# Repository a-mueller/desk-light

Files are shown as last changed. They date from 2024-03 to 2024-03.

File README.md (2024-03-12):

# Desk Light

This is most likely useless for anyone else, hosting it here in case I need to make another one at some point.

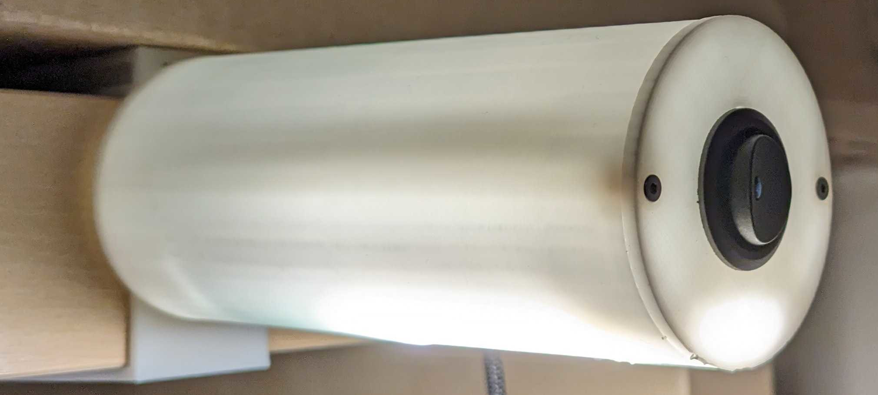
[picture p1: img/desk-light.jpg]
Desk Light


## 3D Models

found in `3dPrinting`

## Board

See KiCad files.

### Schematic

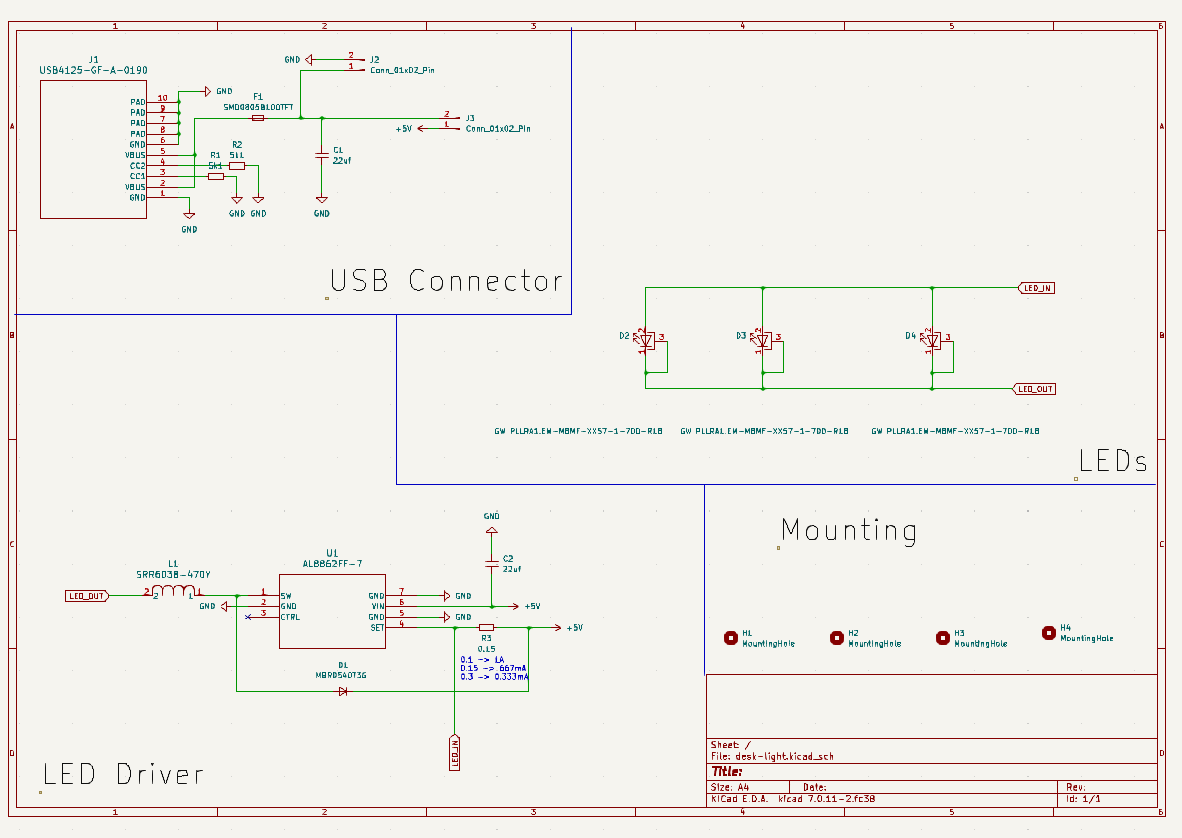
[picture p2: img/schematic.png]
Schematic


### PCB

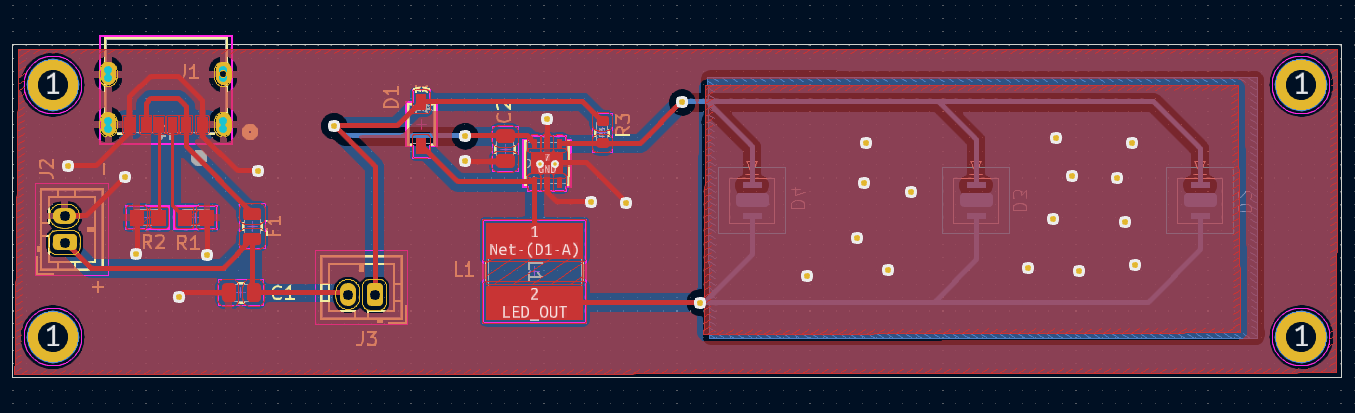
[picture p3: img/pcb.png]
PCB


### BOM

<table>
<tr><td>R1,R2</td><td>5.1k, 0603</td><td></td></tr>
<tr><td>J1</td><td>USB4125-GF-A-0190</td><td>https://uk.farnell.com/global-connector-technology/usb4125-gf-a-0190/usb-conn-type-c-r-a-rcpt-6pos/dp/3777661</td></tr>
<tr><td>J2</td><td>JST PH 2.0 mm</td><td>alternative power, in case no USB connector used</td></tr>
<tr><td>J3</td><td>JST PH 2.0 mm</td><td>On / off switch</td></tr>
<tr><td>C1, C2</td><td>22uf, 0805</td><td></td></tr>
<tr><td>F1</td><td>Fuse 0805, 1A/1.95A</td><td>https://uk.farnell.com/yageo/smd0805b100tft/pptc-reset-fuse-smd-6vdc-0805/dp/4072028?st=smd0805b100tft</td></tr>
<tr><td>D1</td><td>Diode, MBR0540T3G 0.5A, SOD 123</td><td>https://uk.farnell.com/on-semiconductor/mbr0540t3g/diode-schottky-0-5a-40v-sod-123/dp/2101839?st=mbr0540t3g</td></tr>
<tr><td>U1</td><td>Led Driver, AL8862FF-7, 1A</td><td>https://uk.farnell.com/diodes-inc/al8862ff-7/led-dc-dc-driver-buck-u-dfn3030/dp/3946403?st=al8862ff-7</td></tr>
<tr><td>R3</td><td>0.15ohm, 0603</td><td>sets output to 1A</td></tr>
<tr><td>L1</td><td>Inductor, SRR6038-470Y</td><td>https://uk.farnell.com/bourns/srr6038-470y/power-inductor-47uh-0-95a-shielded/dp/2859255?st=srr6038-470y</td></tr>
<tr><td>D2,D3,D4</td><td>LEDs power, GW PLLRA1.EM-M8MF-XX57-1-700-R18</td><td>https://uk.farnell.com/osram-opto-semiconductors/gw-pllra1-em-m8mf-xx57-1-700/led-hb-warm-white-3000k-280lm/dp/3625393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</td></tr>

</table>

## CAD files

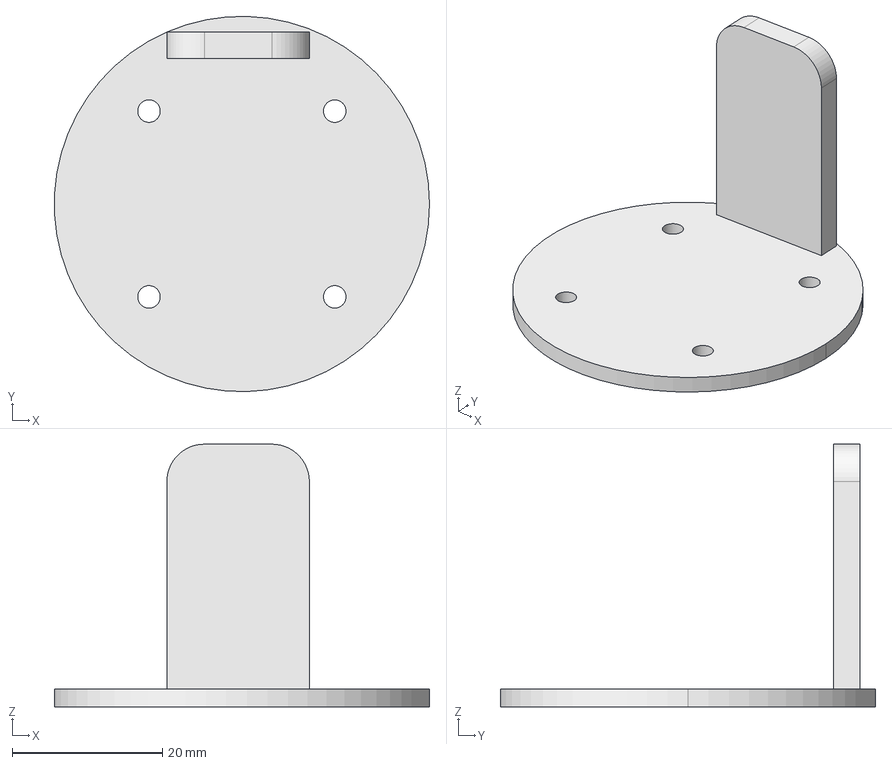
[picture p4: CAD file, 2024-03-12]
3dPrinting/desk-light-v1.FCStd
50.0 x 50.0 x 35.0 mm

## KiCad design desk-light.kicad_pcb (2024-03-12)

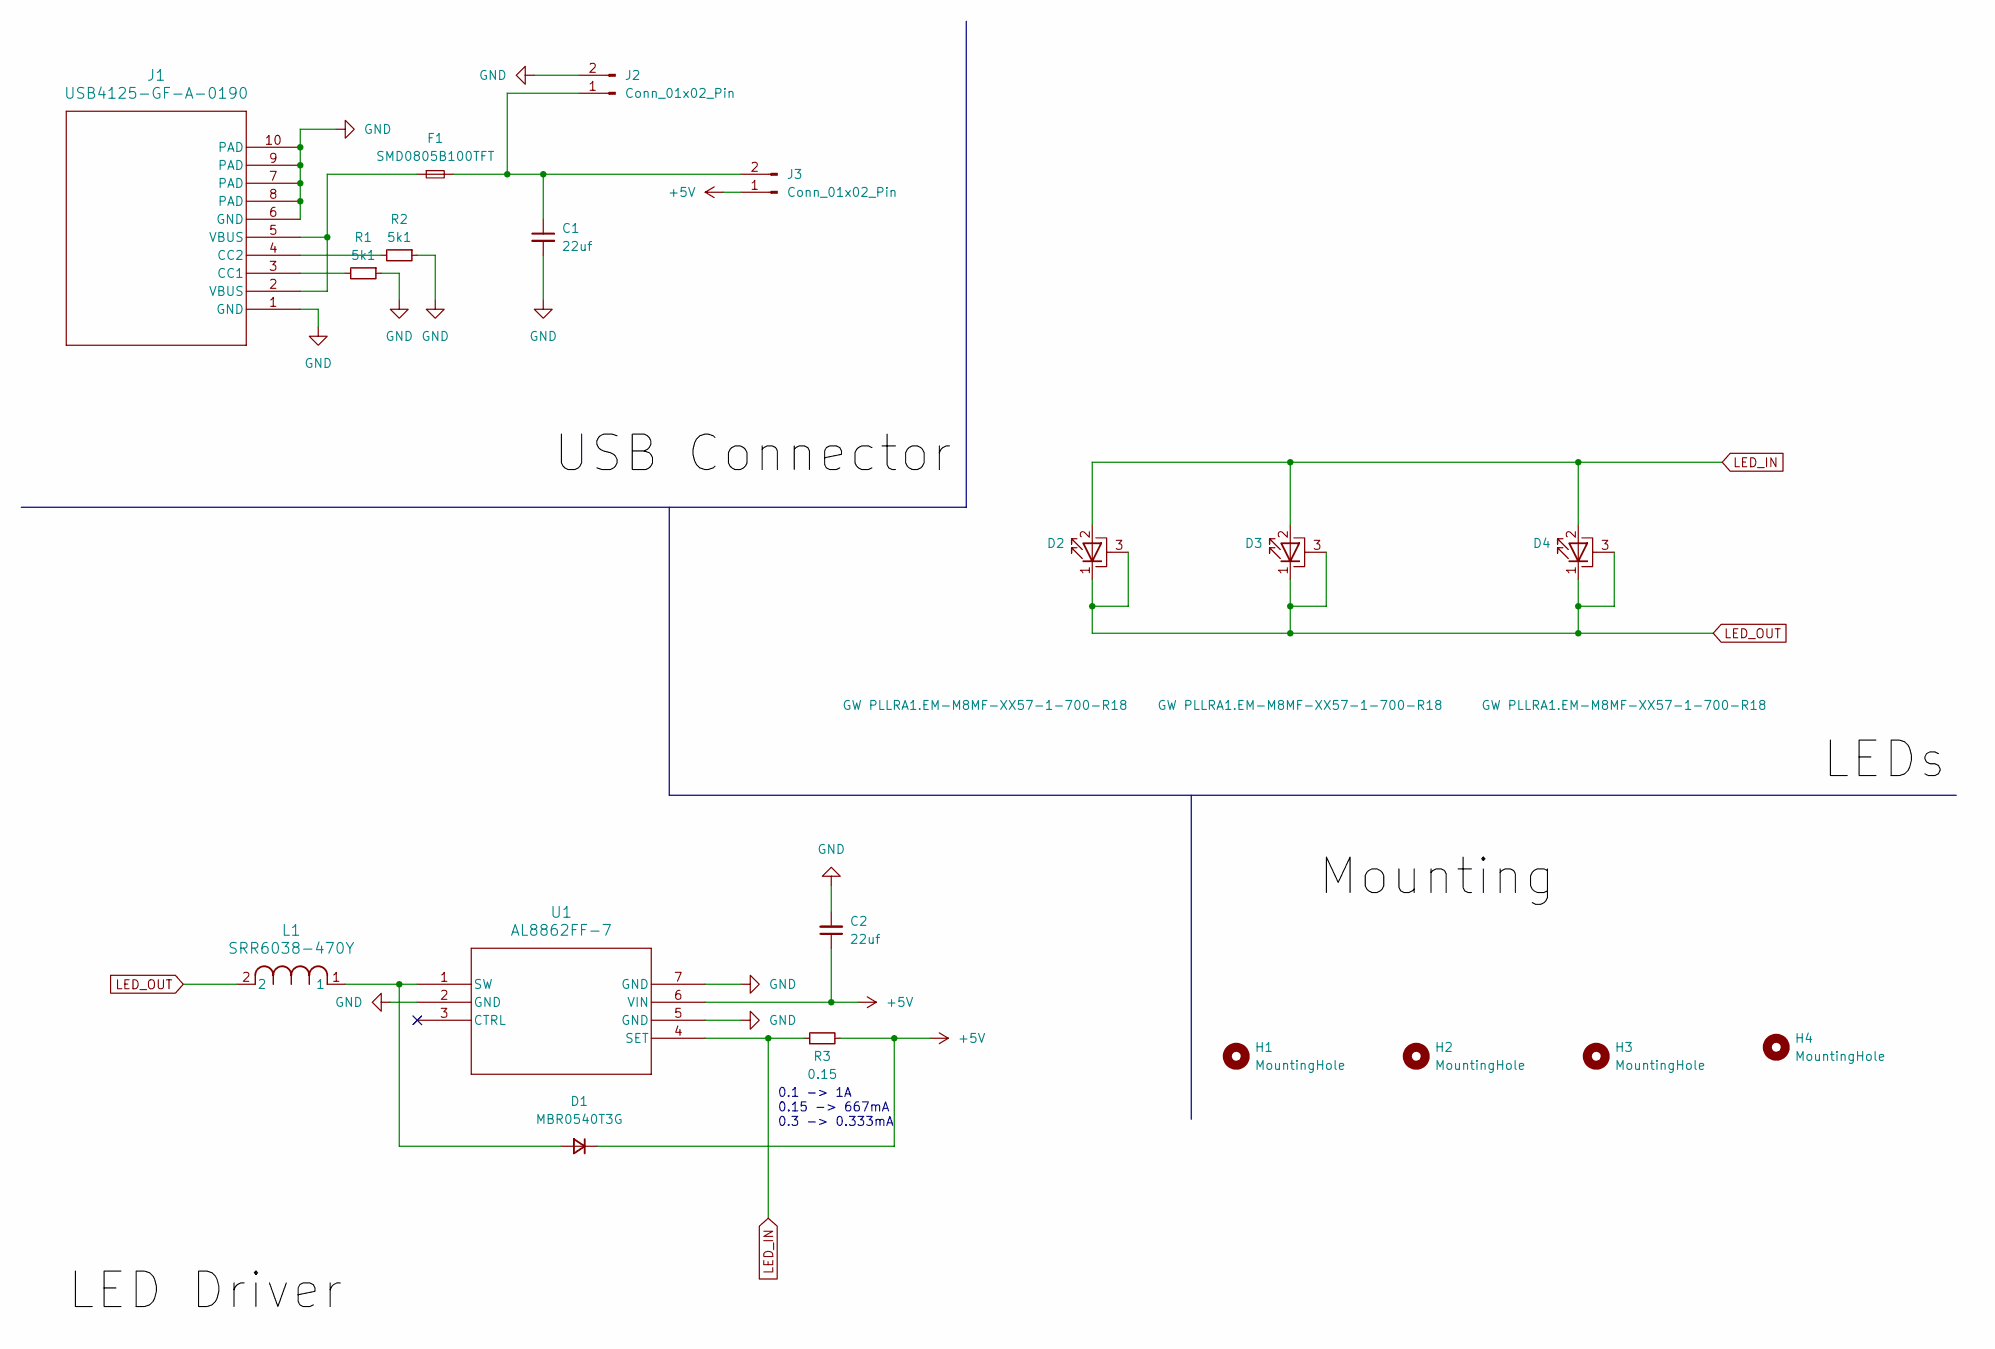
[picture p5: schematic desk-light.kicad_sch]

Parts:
C1, C2: 22uf; C_0805_2012Metric
D1: MBR0540T3G; SOD-123_ONS
D2, D3, D4: GW PLLRA1.EM-M8MF-XX57-1-700-R18; GWPLLRA1.EM
F1: SMD0805B100TFT; Fuse_0805_2012Metric
H1, H2, H3, H4: MountingHole; MountingHole_2.2mm_M2_DIN965_Pad
J1: USB4125-GF-A-0190; CONN6_125-GF-A-0190_GCT
J2, J3: Conn_01x02_Pin; JST_PH_B2B-PH-K_1x02_P2.00mm_Vertical
L1: SRR6038-470Y; IND_BOURNS_SRR6038
R1, R2: 5k1; ERJ6G_PAN
R3: 0.15; R_0603_1608Metric
U1: AL8862FF-7; U-DFN3030-6_DIO

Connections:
+5V: C2.1, D1.1 (K), J3.1, R3.2, U1.6 (VIN)
GND: C1.2, C2.2, J1.1 (GND), J1.6 (GND), J1.7 (PAD), J1.8 (PAD), J1.9 (PAD), J1.10 (PAD), J2.2, R1.1, R2.1, U1.2 (GND), U1.5 (GND), U1.7 (GND)
LED_IN: D2.2 (A), D3.2 (A), D4.2 (A), R3.1, U1.4 (SET)
LED_OUT: D2.1 (K), D2.3 (PAD), D3.1 (K), D3.3 (PAD), D4.1 (K), D4.3 (PAD), L1.2
unnamed: D1.2 (A), L1.1, U1.1 (SW)
unnamed: F1.1, J1.2 (VBUS), J1.5 (VBUS)
unnamed: J1.3 (CC1), R1.2
unnamed: J1.4 (CC2), R2.2
unnamed: C1.1, F1.2, J2.1, J3.2

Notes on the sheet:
0.1 -> 1A 0.15 -> 667mA 0.3 -> 0.333mA

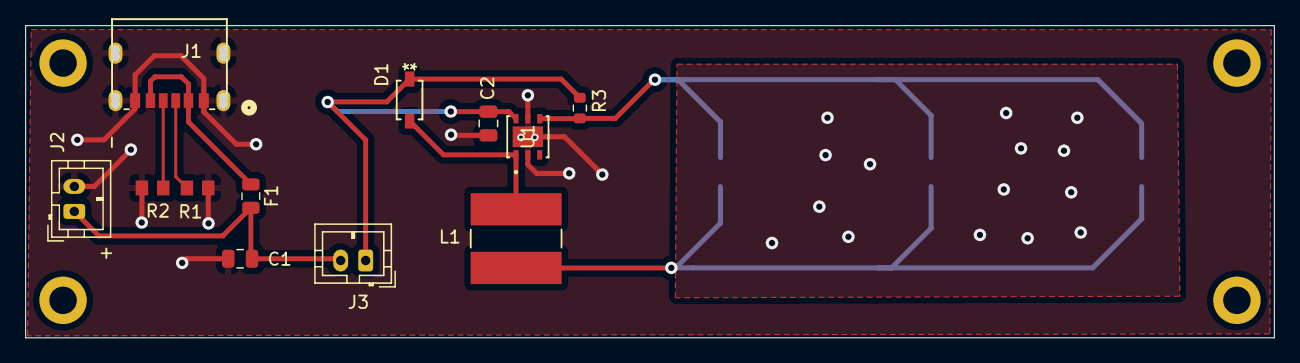
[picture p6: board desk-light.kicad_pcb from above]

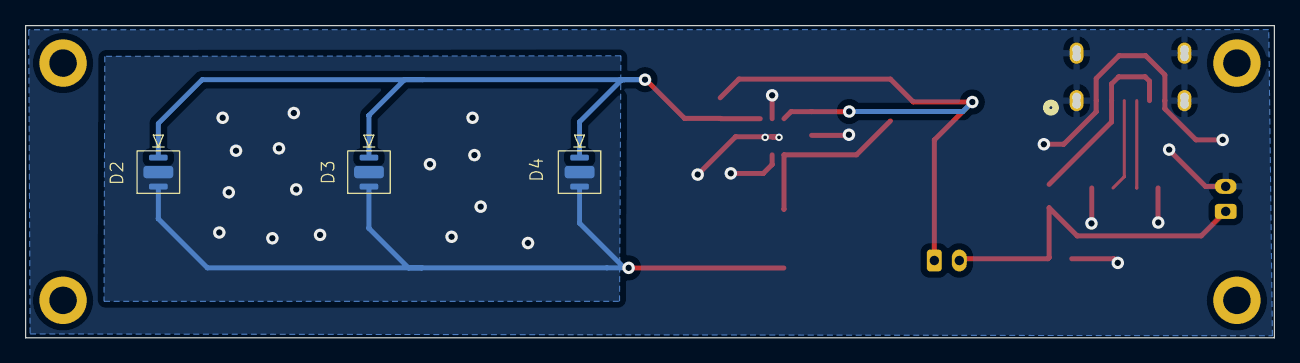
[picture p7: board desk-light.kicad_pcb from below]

Board: 2 copper layers, 100.0 x 25.0 mm, 19 parts (3 on the bottom side), 9 nets.
